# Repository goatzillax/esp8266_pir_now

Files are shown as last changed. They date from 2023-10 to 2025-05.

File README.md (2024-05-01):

# esp8266_pir_now

Rework of an older PIR sensor project with updated goals.

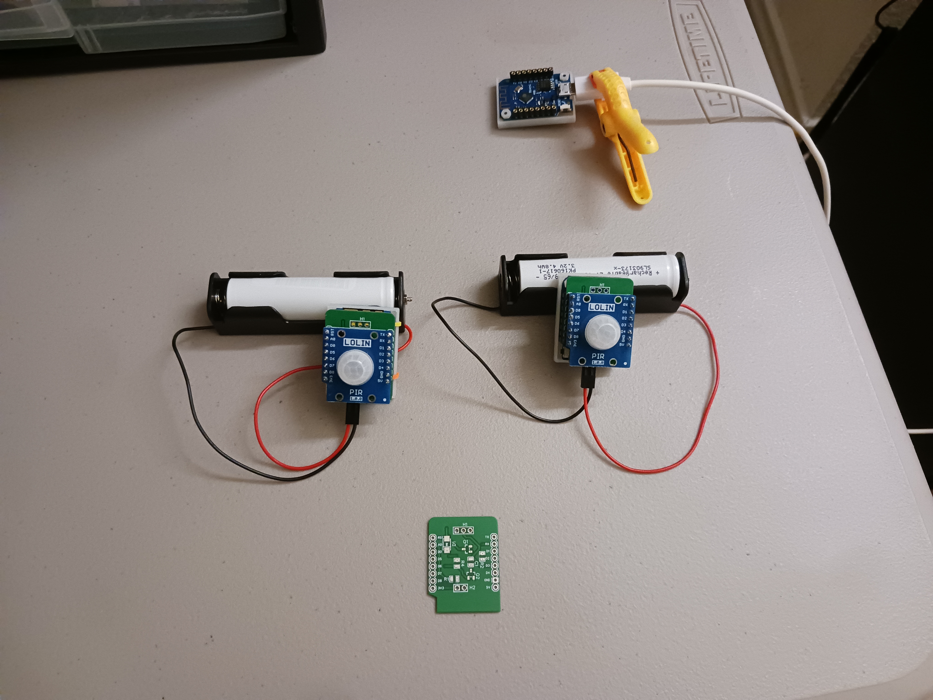
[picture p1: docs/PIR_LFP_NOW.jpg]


## Transmit unit

The system is intended to support multiple transmitter/sensor units in an 'offline' (non-infrastructure) mode in case of remote usage.  Think:  camping.  Don't want no bears sneaking up on me know what im saying i ain't down with that git away from thar, bear u don't know me like that.

All the transmitters/sensors transmit via ESP-NOW and should be powered by a single LiFePO4 cell wired directly into 3.3v.

Upon first power up, the transmitter will scan available channels until a message is successful and then save that channel to RTC memory.

The chip should then enter deep sleep until woken up by PIR detection.

### The Problem with D3

Just realized why deep sleep with a timeout was failing.  It wasn't actually failing, it was because D3 is being used as the PIR input.

D3 must be pulled high at boot time or boot will fail.  Under normal PIR triggering, this is true.

However, if the board wakes up via a deep sleep timeout, the PIR output will still be driving low...  causing boot to fail.

The Wemos shield allows selection of the target GPIO...  but my v1 PCB doesn't because i r dum.

### TODO

* rescan after X amount of failbertz
* add selected channel to message for debugging

## Receiver unit

The receiver unit pretty much has to be running fulltime in order to receive ESP-NOW messages from the sensors.  (i.e. no sleep of any kind, including modem/wifi sleep.)  And while it's doing that, it might as well run a webserver to present controls and events.

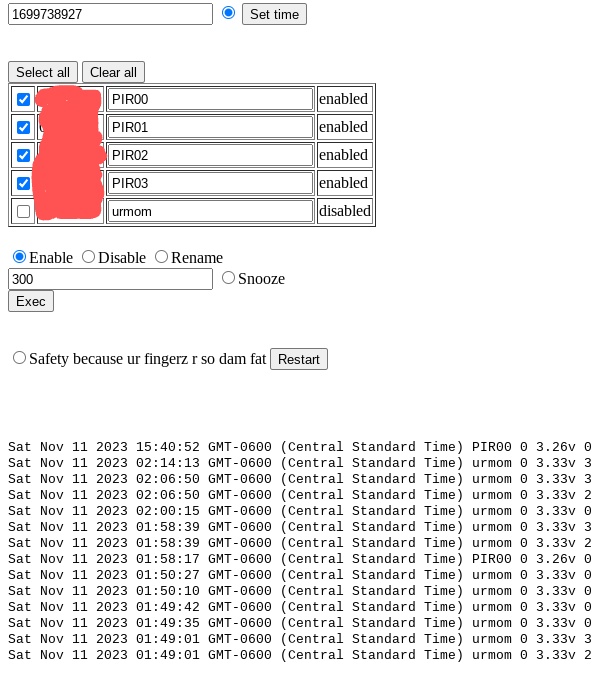
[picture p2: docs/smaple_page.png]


In infrastructure mode:

* fire up NTPClient

In offline mode:

* use form to set time from client

### Files

#### www/history.json

Not a real file in the filesystem, generated on the fly from the ESP's history buffer.

#### www/sensors.json

Real file residing on the filesystem, updated and maintained by the ESP.  Small hands, smell like cabbage, looks like this:

        {
           "0xcacaca" : {
              "name" : "urmom",
              "status" : 0
           }
        }

### Division of work

Currently a lot of tasks are split between the ESP and the web client via Javascript.

The ESP "owns" (writes) both files.  The web client makes a bunch of queries to the ESP through http get methods which is actually kind of cumbersome to program.

The alternative is to let the web client own the sensors.json file, make all manipulations necessary, and then simply upload the file wholesale to the ESP and tell it to refresh.  This is probably less secure but a lot less cumbersome in the ESP code because writing hooks for all that shit gets tedious and the same tasks are slightly easier in Javascript on the client.  Congrats to c++ for being slightly worse than Javascript.

Would need to add some form of synchronization to the webserver to avoid collisions if that's even possible and avoid stale data usage by the client (generation/sequence number).

### TODO

* How to deal with millis() rollover in offline mode
* Might need to deal with the 2038 rollover.  Helo 64bit epox?

## Hardware

### Lolin D1 Mini

https://www.wemos.cc/en/latest/d1/d1_mini.html

Everything currently targeted at the Lolin D1 Mini because dats wat I has on hand.

The original branded hardware...  acts kind of fishy sometimes.  The ADC resistor seems off and the reset line is touchy even with their own shields.  Weirdly, the clones seem to actually work better, but are ... dimensionally challenged sometimes.

### PIR Sensors

#### Lolin PIR Shield

https://www.wemos.cc/en/latest/d1_mini_shield/pir.html

Directly wires the PIR sensor output to D3 and...  that's about it.  No deep sleep/reset support because reason.

TODO:  wat's the timeout?

#### Other PIR Sensors

There are a bunch of DIY modules based on AM312 sensors.  For low power single-cell LFP usage, you'll want to pull the LDO regulator on the PCB and directly wire VIN.

Not tested yet.

TODO:  wat's the timeout?

### Reset Circuitry

I need to revisit the docs for reset, but in general in order to reset I think the ESP8266 needs to see a transition from high to low (and stay low for 100ns?) on the reset line.

The PIR sensors all just pull high when motion is detected.  So what's needed is typically a capacitor at the gate of a FET which then pulls the reset line low for RC-constant amount of time.  Sometimes called an edge detector.

Also need a diode to shunt the reverse voltage against the gate when the PIR signal goes low.

If timer functionality is desired, a diode is placed between D0 and RESET so it can also directly pull reset low.

#### Dat Body Diode

What's sort of vaguely missing is if the code runs for longer than the timeout period of the PIR signal.  If another edge comes in from the PIR...  you might get reset with your pants down.  And nobody wants to see that, not even the bear.

So you need to pull the gate of the reset FET low to prevent further resets while you're working.  And since you already need a diode shunt the reverse voltage on the gate of the reset FET...  just throw a second transistor (body diode) in its place.

#### Even More Reset Hijinx

* https://github.com/esp8266/esp8266-wiki/wiki/Boot-Process
* https://randomnerdtutorials.com/esp8266-pinout-reference-gpios/

The gates of Q1 and Q2 are both pulled low in my PCB, so if I want to reuse them, I can't use them on boot-critical pins.  I.e. these are completely no bueno:

* D4/GPIO2 (Boot selector - High)
* D3/GPIO0 (Boot selector - High) This is the PIR output, which would be high anyways on a deep sleep reset
* TX/GPIO1 (? - High)
* D8/GPIO15 (Pulled to ground, boot fails if pulled high) - Might be OK if pulled to ground?

Side-eye:

* D0/GPIO16 (High at boot) - this is used for deep sleep wakeup though
* RX/GPIO3 (High at boot)

PCB has a solder jumper to select from

* RX
* D5
* D6
* D7

Options for adding a buzzer for receiver:

1.  ~~GPIO can sink 20ma, so deadbug a 220ohm resistor in series and connect Buzzer+ to H1 3.3v and Buzzer- to D3.  Use D3 as active low output.  This isn't full volume, but probably don't actually need full volume.~~  This pretty much sucks; the buzzer does squat at that current.
2.  Connect Buzzer+ to H1 3.3v, Buzzer- to Q2 Drain (so the R3/R2/Q1 net).  Solder jumper D5/6/7 and use as active high output.  Pain in the ass, but preserves D3.  5v buzzer running at 3.3v is still pretty loud.

### PCB

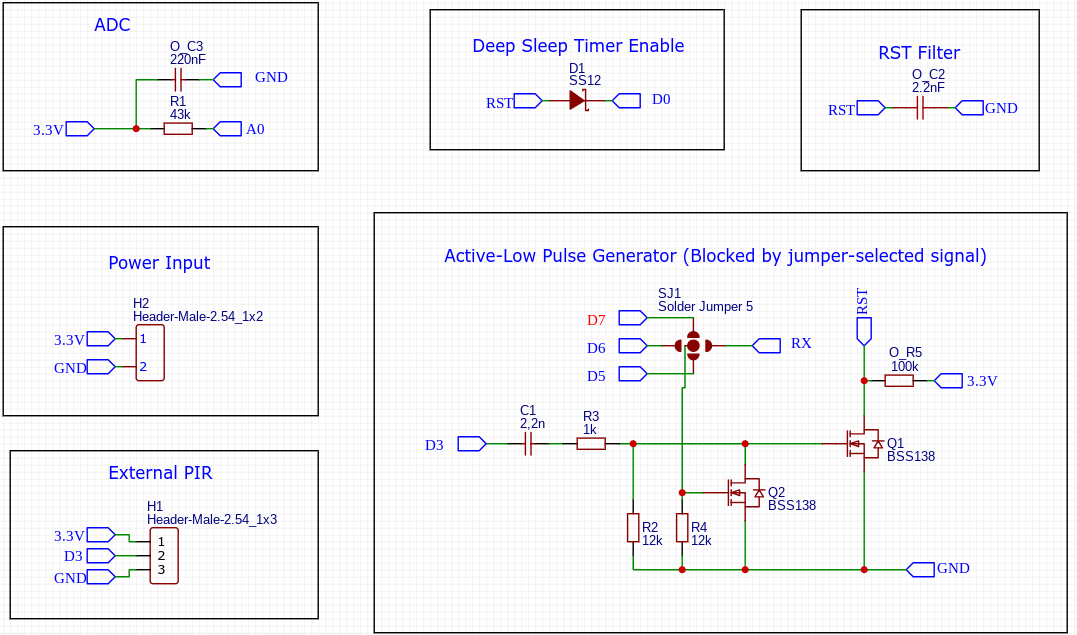
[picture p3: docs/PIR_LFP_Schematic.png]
PCB


#### TODO

* Name the parts better
* Put optional parts on back, required parts on front (looking at you, R3)
* Castellated edges
* Space for 3.5v zener diode
* Space for buzzer (avoid I2C pins) (for RX)
* I2C RTC header (for RX)
* Switch to FET arrays (2x for reset line+latch, 1x for buzzer, 1x inverter?)
* Space for power capacitor
* Bigger vias
* Spicy simulation results

### Case

TX V1 case based on Lolin D1 Mini + 18650 LFP cell holder + custom PCB stack

Can't figure out how to embed the STL viewer in github markdown.

Viewer doesn't sport binary apparently, nor does it support .gz files.  Neat.  It's nearly the end of 2023, yall.

#### TODO

* total weatherproofing and sealing
* external power input
* external reset

### RCWL-0516

The RCWL-0516 is a curious animal.

https://github.com/jdesbonnet/RCWL-0516

Notable things:

* Takes 4-28v.  Apparently needs higher, like 5v, to run reliably.
* Has an internal regulator, probably linear.  3.3v output is limited to 100ma.

So to use this I'd probably bump up to a 2s LiFePO4 battery, which complicates matters.

Easiest thing to do might be to use a step down regulator with an enable to produce 3.3v.

Tie the regulator enable to the output of the RCWL-0516 and also allow the microcontroller to latch it high as long as it needs.  Might be nice to know if Vout was open drain or push-pull.

This saves power by disabling the regulator, however it also means I can't use RTC memory since power is totally shut down.  Which means I need an alternate way to rescan for the ESP-NOW channel.  Maybe a bootstrap gpio with momentary switch.

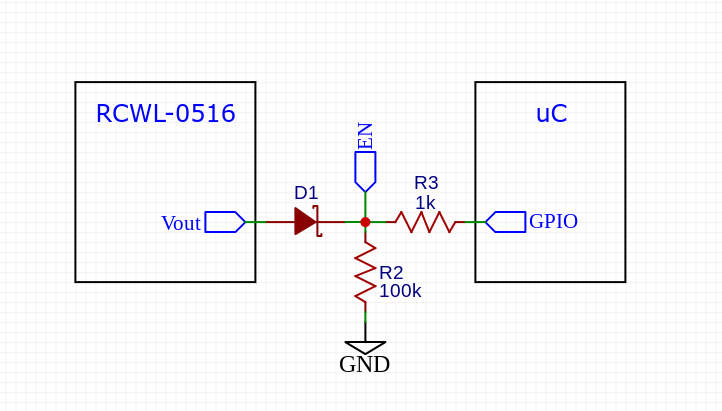
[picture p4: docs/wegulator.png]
wegulator


So the RCWL-0516 triggers Vout and turns on the regulator.  The uC has 2 seconds to boot up and latch the EN for itself.  When it's done, it can deassert EN.

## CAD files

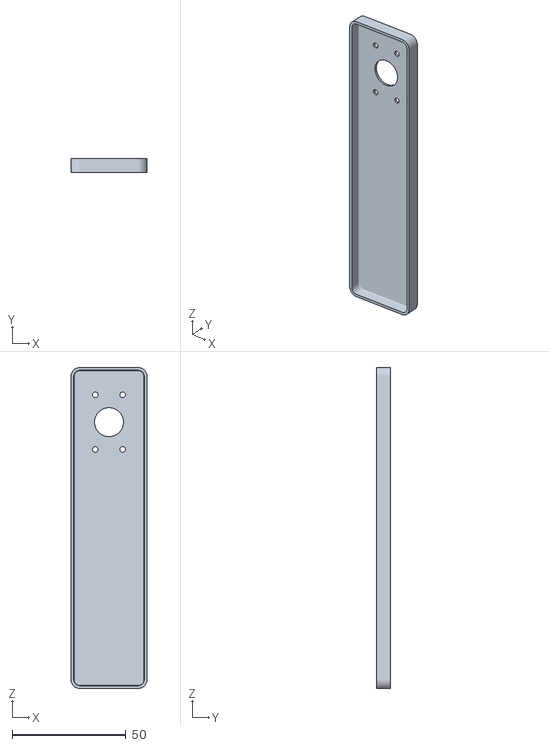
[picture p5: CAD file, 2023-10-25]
hardware/PIR_LFP_case_v1-top.stl
33.4 x 6.00 x 141.0

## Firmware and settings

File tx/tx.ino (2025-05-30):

#include <ESP8266WiFi.h>
#include <espnow.h>
#include <RTCMemory.h>
#include <ArduinoJson.h>
#include "esp8266_pir_now.h"

//#define DEBUG

#define USE_SHT
#ifdef USE_SHT
#include <WEMOS_SHT3X.h>

SHT3X sht30(0x45);
float cTemp;
float humidity;

#endif

#define ADC_NETWORK (1145+220+100)
#define ADC_OFFSET -5

//  ESPRESSIF CORE IS STILL DICKED UP BUT YOU CAN FORCE THE CHANNEL WITH WIFI_SET_CHANNEL()

//  by the way, esptool.py under Arduino is broken past 2.5.0 for uploading LittleFS.  Great job guys.  And it fucking changes the baud to 408000 for no apparent reason.
//  only way to get it to work is to apparently hit it with --no-stub but then it uses the factory rom which apparently only does 115200 baud.

#define PIR_PIN D3

struct_PIR_msg PIR_msg;

#define LATCH_PIN D5
int session_tries;
#define MAX_TRIES 3

enum e_xmit_state {
   XMIT_IDLE,
   XMIT_STARTED,
   XMIT_FINISHED
};

enum e_xmit_state xmit_state;

int wifi_search_chan;

typedef struct {
   uint32_t fails;
   int wifi_chan;
   uint8_t masterAddr[6];
} rtcData;

rtcData *data;

RTCMemory<rtcData> rtcMemory;

void OnDataSent(uint8_t *mac_addr, uint8_t sendStatus) {
   digitalWrite(LED_BUILTIN, HIGH);
   if (sendStatus == 0) {
      //Serial.println("Delivery success");
      data->fails = 0;
   } else {
      //Serial.println("Delivery fail");
      data->fails++;
   }
   xmit_state = XMIT_FINISHED;
}


void deepSleep(bool save=true) {
   if (save) {
      rtcMemory.save();
   }
   digitalWrite(LATCH_PIN, LOW);
   ESP.deepSleep(30*1000000);  //  man this is some unreliable shit
}

void setup() {

   //  todo:  for starters, use a better board with EN pinned out and PIR not on a literal fucking bootstrap pin.
   //  the very first thing is to look at the voltage.  If it's
   //  below threshold (say 2.9v) immediately go back to deep sleep.
   //  there's really not that much energy under 3.0v anyways.
   //  there should also be a hardware voltage supervisor, but we prefer
   //  to put ourselves to sleep instead of getting pantsed.  particularly
   //  if we're in the middle of some flash routine.  totally uncool man.
   //  lvc:  drops EN at 2.8v.
   //  code:  go back to sleep at 2.9v.

   int adcValue = analogRead(A0);
   uint32_t voltage = (adcValue * ADC_NETWORK / 1023) + ADC_OFFSET;
//  old guard was 290
#ifdef BATTERY_GUARD
   if (voltage < BATTERY_GUARD) {
      deepSleep(false);
   }
#endif

   Serial.begin(115200);

#ifdef DEBUG
   delay(1000);
   Serial.println();
#endif

   pinMode(D0, WAKEUP_PULLUP);
   pinMode(LED_BUILTIN, OUTPUT);
   pinMode(LATCH_PIN, OUTPUT);
   digitalWrite(LATCH_PIN, HIGH);

   WiFi.disconnect();
   WiFi.persistent(false);
   WiFi.mode(WIFI_STA);

   if (esp_now_init() != 0) {
      Serial.println("Error initializing ESP-NOW");
      return;
   }

   if (rtcMemory.begin()) {
      //  this doesn't work.  D3 is a bootstrap pin so it must be high to even wake up.
      pinMode(PIR_PIN, INPUT);
      if (!digitalRead(PIR_PIN)) {
         deepSleep(false);
      }
      data = rtcMemory.getData();
   } else {
      data = rtcMemory.getData();
      data->fails = 0;
      data->wifi_chan = -1;  // pull this from config.json ... probably.

      LittleFS.begin();
      StaticJsonDocument<256> cfg;
      File file = LittleFS.open("/config.json", "r");
      auto error = deserializeJson(cfg, file);

      file.close();

      if (error) {
         Serial.println("json error");
         deepSleep(false);  //  what happens when we begin() but never save?  debug later.
      }

      data->wifi_chan = cfg["esp-now"]["channel"];

      //  JSON doesn't handle native hex numbers for some shitty esoteric reason.  trash.

      for (int i=0; i<6; i++) {
         data->masterAddr[i] = (uint8_t) strtoul(cfg["esp-now"]["master"][i], NULL, 16);
      }

      file.close();
   }  // "first boot" setup

   esp_now_set_self_role(ESP_NOW_ROLE_CONTROLLER);
   esp_now_register_send_cb(OnDataSent);

   xmit_state = XMIT_IDLE;

   //  like loop preload
   wifi_search_chan = data->wifi_chan == -1 ? 1 : data->wifi_chan;
#ifdef DEBUG
   Serial.println("wifi chan: " + String(data->wifi_chan));
#endif
   if (esp_now_add_peer(data->masterAddr, ESP_NOW_ROLE_SLAVE, wifi_search_chan, NULL, 0)) {
      Serial.println("error adding peer");
   }
   wifi_set_channel(wifi_search_chan);

   session_tries = 0;
}

void loop() {
   switch (xmit_state) {
      case XMIT_FINISHED:
         if (data->wifi_chan == -1) {
            if (data->fails == 0) {
               data->wifi_chan = wifi_search_chan;
               deepSleep();  // defo save the channel
            }  //  message succeeded
            else {
               //  OK so obviously you can only have one peer associated with a channel...  ?
               if (esp_now_del_peer(data->masterAddr)) {
                  Serial.println("error deleting peer");
               }
               wifi_search_chan += 1;
               if (wifi_search_chan > 11) {
                  wifi_search_chan = 1;
               } //  halt but do not catch fire?
               wifi_set_channel(wifi_search_chan);
               if (esp_now_add_peer(data->masterAddr, ESP_NOW_ROLE_SLAVE, wifi_search_chan, NULL, 0)) {
                  Serial.println("error adding peer");
               }
            }  //  message failed, cycle channel
         }  //  in search mode
         else {
            if ((data->fails != 0) && (session_tries < MAX_TRIES)) {
               rtcMemory.save();
               delay(random(500,1000));
            }  //  random backoff and retry because deepsleep with timeout seems buggy
            else {
               deepSleep();  // save failberts
            }
         }  //  not in search mode
         xmit_state = XMIT_IDLE;
         break;
      case XMIT_IDLE:
         {
            int adcValue = analogRead(A0);
            uint32_t voltage = (adcValue * ADC_NETWORK / 1023) + ADC_OFFSET;

            PIR_msg.id = 0;  //  actually we have a mac on the RX end so...  this is more like a cmd
            PIR_msg.voltage = (uint16_t)(voltage);
            PIR_msg.failberts = data->fails;
#ifdef USE_SHT
            if (sht30.get()==0) {
               //Serial.println(String(sht30.cTemp)+"C");
               //Serial.println(String(sht30.humidity)+"%");
               PIR_msg.temperature = (int) (sht30.cTemp * 10);
               PIR_msg.humidity    = (int) (sht30.humidity * 10);
#ifdef DEBUG
               Serial.println(String(PIR_msg.temperature/10)+"C");
               Serial.println(String(PIR_msg.humidity/10)+"%");
               delay(100);
#endif
            } else
#endif
            {
               PIR_msg.temperature = 1000;  //  bogus value
               PIR_msg.humidity = 1100;     //  bogus value
            }
            if (data->wifi_chan == -1) {
               Serial.print("searching channel ");
               Serial.println(wifi_search_chan);
            }

            xmit_state = XMIT_STARTED;
            session_tries++;
            digitalWrite(LED_BUILTIN, LOW);
            esp_now_send(data->masterAddr, (uint8_t *)&PIR_msg, sizeof(PIR_msg));
         }
      case XMIT_STARTED:
         delay(100);
         break;
      default:
         Serial.println("WAT?");
         break;
   }
}

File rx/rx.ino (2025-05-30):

#include <CircularBuffer.h>
#include <ESP8266WiFi.h>
#include <espnow.h>
#include <NTPClient.h>
#include <WiFiUdp.h>
#include <ESPAsyncTCP.h>
#include <ESPAsyncWebServer.h>

#define USE_OTA
#ifdef USE_OTA
#include <ElegantOTA.h>
#endif

#include <ArduinoJson.h>
#include <LittleFS.h>
#include "esp8266_pir_now.h"
#include "sekritz.h"

const char compile_date[] = __DATE__ " " __TIME__;

typedef struct {
   uint32_t src;	//  last 3 bytes of MAC
   uint32_t timestamp;	//  seconds since epoch.  pretty sure I don't need more than second resolution
   struct_PIR_msg msg;
} struct_log_entry;

struct_log_entry log_entry;

CircularBuffer<struct_log_entry,192> history;

#define BUZZER_PATTERN_LEN  6
#define BUZZER_DELAY        1000
const int buzzer_pattern[BUZZER_PATTERN_LEN] = { HIGH, LOW, HIGH, LOW, HIGH, LOW };

int buzzer_state=BUZZER_PATTERN_LEN;
unsigned long buzzer_start;

//  Receiver don't got no PIR on itself
#define BUZZER_PIN	D5

void start_buzzer() {
   if (buzzer_state == BUZZER_PATTERN_LEN) {
      buzzer_state = 0;
      buzzer_start = millis();
   }
}

unsigned long reset_requested;

void cycle_reset() {
   if (reset_requested == 0) {
      return;
   }
   if (millis() - reset_requested > 5000) {
      ESP.reset();
   }
}

//  I like writing schedulers.  I really really like writing schedulers.
void cycle_buzzer() {
   if (buzzer_state == BUZZER_PATTERN_LEN) {
      return;
   }

   digitalWrite(BUZZER_PIN, buzzer_pattern[buzzer_state]);
   digitalWrite(LED_BUILTIN, !buzzer_pattern[buzzer_state]);

   if (millis() - buzzer_start > BUZZER_DELAY) {
      buzzer_state++;
      buzzer_start = millis();
   }
}

#if 0
String mactostr(uint8_t *mac) {
   //  I LOVE CPP
   char macStr[18] = { 0 };
   sprintf(macStr, "%02X:%02X:%02X:%02X:%02X:%02X", mac[0], mac[1], mac[2], mac[3], mac[4], mac[5]);
   return String(macStr);
}
#endif

//  offloaded name lookup completely to the client
String longtoname(uint32_t longmac) {
   return String(longmac, HEX);
}

String mactoname(uint8_t *mac) {
   //  prtty much just care about last 3 bytes
   uint32_t i=mac[5] + (mac[4]<<8) + (mac[3]<< 16);
   return longtoname(i);
}

StaticJsonDocument<1024> sensors;

//  json file functions from the ESP side:
//  add newly found sensors to the assoc array
//  store persistent status

//  load seems to be a pretty "free" operation
void loadSensors() {
   File file = LittleFS.open("/www/sensors.json", "r");

   deserializeJson(sensors, file);

   file.close();
}

//  this is less free...
void saveSensors() {
   File file = LittleFS.open("/www/sensors.json", "w");
   if (!file) {
      return;
   }
   serializeJson(sensors, file);
   file.close();
}

WiFiUDP		ntpUDP;
NTPClient	timeClient(ntpUDP);

unsigned long	epoch;  //  offline substitute for NTPClient.

AsyncWebServer webserver(80);

#define WIFI_STA_WAIT 10000

//  pretty sure I would be better served with a getNames() or something but of course that doesn't exist
//  i.e. snooze is a setstatus(2) plus start and duration...  bleh fix later.
boolean setstatus(AsyncWebServerRequest *request, uint32_t value) {
   //  all params starting with "0x" are names
   boolean wb = false;
   for (int i=0; i<request->params(); i++) {
      AsyncWebParameter *p = request->getParam(i);
      if (p->name().substring(0, 2) == "0x") {
         if (sensors.containsKey(p->name())) {
            sensors[p->name()]["status"] = value;
            wb = true;
         }
      }
   }
   return wb;
}

//  yeah...  fixme plox
boolean setNames(AsyncWebServerRequest *request) {
   //  all params starting with "0x" are names
   boolean wb = false;
   for (int i=0; i<request->params(); i++) {
      AsyncWebParameter *p = request->getParam(i);
      if (p->name().substring(0, 2) == "0x") {
         if (sensors.containsKey(p->name())) {
            sensors[p->name()]["name"] = request->arg(p->name());
            wb = true;
         }
      }
   }
   return wb;
}

boolean setSnooze(AsyncWebServerRequest *request, uint32_t tstart, uint32_t duration) {
   //  all params starting with "0x" are names
   boolean wb = false;
   for (int i=0; i<request->params(); i++) {
      AsyncWebParameter *p = request->getParam(i);
      if (p->name().substring(0, 2) == "0x") {
         if (sensors.containsKey(p->name())) {
            sensors[p->name()]["status"] = 2;
            sensors[p->name()]["start"] = tstart;
            sensors[p->name()]["duration"] = duration;
            wb = true;
         }
      }
   }
   return wb;
}

void infra_setup() {
   // Begin LittleFS
   if (!LittleFS.begin())
   {
      Serial.println("error initializing littlefs");
      delay(5000);
      ESP.reset();
   }

   StaticJsonDocument<256> cfg;
   File file = LittleFS.open("config.json","r");
   deserializeJson(cfg, file);
   file.close();

   WiFi.begin(String(cfg["wifi"]["sta"]["ssid"]), String(cfg["wifi"]["sta"]["psk"]));

   unsigned long wifi_start_time=millis();
   reset_requested = 0;  //  extremely low likelihood of hitting this exactly at zero
   

   while (WiFi.status() != WL_CONNECTED) {
      if (millis() - wifi_start_time > WIFI_STA_WAIT) {
         break;
      }
      delay(100);  //  get the feeling this is needed...
   }
   //  schitt or get off the pot time
   if (WiFi.status() == WL_CONNECTED) {
      Serial.println(WiFi.localIP());
      timeClient.begin();  //  dis feels optional but whatevs
   }
   else {
      WiFi.disconnect();
      //  no longer in infra mode (forever?)
      //  Scan for clearest channel?
      WiFi.softAP(String(cfg["wifi"]["ap"]["ssid"]), String(cfg["wifi"]["ap"]["psk"]), cfg["wifi"]["ap"]["chan"], 1);   //  ERROR CHECKING IS 4 SUCKAZ
      Serial.println(WiFi.softAPIP());
   }

   //  kekeke

   webserver.on("/action_page.php", HTTP_GET, [](AsyncWebServerRequest *request) {
      AsyncWebParameter *p = NULL;
      if (request->hasParam("cmd")) {
         p = request->getParam("cmd");
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

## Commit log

2023-10-23 Add ADC read and other stuff
    Tested on real hardware... which I should probably document
2023-10-23 not that this matters, but bug fix
    [tx.ino]
2023-10-25 major doc update and add case STL files
    [PIR_LFP_case_v1-top.stl]
2023-10-26 add buzzer support
    getting tired of typing the word "buzzer"
    [rx.ino]
2023-10-28 tested with physical buzzer
    using an n-channel fet to drive the buzzer now so the logic has
    to be inverted; still using LED as an alternate indicator.
    also make softap hidden n stuff because bearz
    [rx.ino]
2023-11-10 pile of new features
    add elegantota
    add history.json
    rejiggered cmd
    fix up other stuff to match new html
    add reset
    [rx.ino]
2023-11-10 fix unnamed sensor in history list
2023-11-11 implemented all de functions through teh client
    load/save json from arduino side
    enable
    disable
    rename
    snooze
2023-11-23 swap cornfig to json
    [tx.ino]
2023-12-19 increase sensors json buffer size
2025-05-30 pull wifi channel from json. mostly useful for broadcast mode, which really is the only mode that works with the current Arduino lib thx to espressif just giving up on esp8266.
2025-05-30 tweak tx adc calcs
